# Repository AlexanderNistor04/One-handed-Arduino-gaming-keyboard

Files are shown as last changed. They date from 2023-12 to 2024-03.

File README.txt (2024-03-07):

This repository is for a 3D printed one handed gaming keyboard with a thumbstick and a small display. The keyboard has 36 keys (the button inside the thumbstick is the 36th key) and isn't meant to be used for typing but rather for gaming or other programs which don't require a full keyboard. 
The keyboard is built off of an Arduino pro micro with a micro usb port and has a male micro usb to female usb c internal adapter to allow the user to connect the keyboard to their computer with a usb c cable. The program for the Arduino is written in c++ and is included in this repository. 
The thumbstick functions as a mouse by default, moving the stick moves the cursor and clicking on the stick corresponds to a left click. Holding shift and clicking corresponds to a right click. 
All of the circuit boards are custom and their Gerber files are included. The circuits don't have any components on them, but were designed to have the user hand solder each component. The keyboard uses smd neopixel leds, which are the most difficult component to hand solder. The keyboard is designed to fit 3 pin mechanical keyboard switches and is made for hotswap switch sockets.
The previous iterations of the design are included as well, though many are not entirely complete and some files have been lost. 

This link leads to a MakerWorld model with the stl files of the latest version: https://makerworld.com/en/models/233790
This link leads to a thingiverse item with the stl files of the latest version of the 3d models: https://www.thingiverse.com/thing:6422238

Parts:
- arduino pro micro (https://www.amazon.com/gp/product/B01MTU9GOB/ref=ppx_yo_dt_b_search_asin_title?ie=UTF8&psc=1)
- male micro usb to female usb c adapter (https://www.amazon.com/Adapter-KUXIYAN-Connector-Compatible-Devices-Black/dp/B07VBV1PY5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)
- monochrome oled 12c display (https://www.amazon.com/gp/product/B08KLMJDGH/ref=ppx_yo_dt_b_search_asin_title?ie=UTF8&psc=1)
- 35 * 0.1uF ceramic capacitor (https://www.amazon.com/gp/product/B00RT02YIU/ref=ppx_yo_dt_b_search_asin_title?ie=UTF8&psc=1)
- 35 * WS2812B neopixel LED (https://www.amazon.com/gp/product/B00YC7ZXRM/ref=ppx_yo_dt_b_search_asin_title?ie=UTF8&psc=1)
- 36 * through-hole rectifier diode (https://www.amazon.com/gp/product/B071YWNBVM/ref=ppx_yo_dt_b_search_asin_title?ie=UTF8&psc=1)
- 470 ohm through hole resistor
- 36 * gateron yellow mechanical keyboard switche (you can use any full size 3-pin mechanical keyboard switch) (https://www.amazon.com/gp/product/B08JPJX296/ref=ppx_yo_dt_b_search_asin_title?ie=UTF8&psc=1)
- 35 * gateron mechanical switch hot-swap socket (https://www.amazon.com/gp/product/B0972HB9GY/ref=ppx_yo_dt_b_search_asin_title?ie=UTF8&psc=1)
- mechanical keyboard keycap set (I used a hyperx pudding keycap set but you can use any mechanical keyboard keycap set) (https://www.amazon.com/gp/product/B087QTR4CT/ref=ppx_yo_dt_b_search_asin_title?ie=UTF8&psc=1)
- screw-in keyboard stabilizer kit (https://www.amazon.com/gp/product/B08MWDGBJ8/ref=ppx_yo_dt_b_search_asin_title?ie=UTF8&psc=1)
- dual potentiometer analog thumbstick w/ button (https://www.amazon.com/gp/product/B06XH1NTFY/ref=ppx_yo_dt_b_search_asin_title?ie=UTF8&psc=1)
- thumbstick cap (https://www.amazon.com/gp/product/B083P4K9YR/ref=ppx_yo_dt_b_search_asin_title?ie=UTF8&psc=1)
- male pin headers (https://www.amazon.com/gp/product/B074HVBTZ4/ref=ppx_yo_dt_b_search_asin_title?ie=UTF8&psc=1)
- 9 * m3 nuts and bolts (https://www.amazon.com/Socket-Screws-Assortment-Button-Assorted/dp/B0BMQGV4SW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)

Building Instructions:
1. Solder the neopixel LEDs onto the primary circuit board. It's easiest to solder the neopixels first because they're the most dificult component to solder and should be done on a flat pcb, though this is not strictly necessary. The neopixels need to be oriented such that the small triangle indent on each neopixel is on the bottom right corner. 
2. Solder the diodes to the primary and secondary pcbs. The annode (negative side) (the side with the silver making) should be facing downwards for each diode. The diodes can be on either the front or the back of the pcb, except for the diode next to the shift key and the diode on the secondary pcb, which must be facing the backside of the board to avoid interference with other components.
3. Solder the hotswap sockets to the back of the primary pcb. The sockets should only be able to fit in one way, so there's no need to worry about soldering them backwards.
4. Solder the capacitors onto the back of the primary board. The capacitors must be on the backside of the board to not interfere with the keys. Most small, ceramic capaitors are not polar, so the capacitors can be soldered either way.
5. Solder the arduino to the back of the primary pcb. When looking at the back of the primary pcb, the port of the arduino should be facing right.
6. Solder the resistor to the back of the primary pcb.
7. Solder the display to the front of the primary pcb. Place the screen spacer 3d printed piece underneath the display while soldering to help keep the display level. Keep the spacer underneath the display to ensure it stays in place while in use. 
8. Solder the thumbstick to the secondary pcb. 
9. Solder the secondary pcb to the main pcb using some pin headers.
10. Attach the shift key stabilizer to the pcb.
11. Insert the female usb c end of the adapter into the main body of the keyboard such that the rest of the adapter lays on the inside of the body and the female end is flush with the outside of the body. It helps to heat the inside of the hole with a soldering iron to assist this process. It should be a very stiff fit and can be difficult to insert. 
12. Plug the male micro usb end of the adapter into the arduino and place the pcb into the main body.
13. Place the thumbstick cap onto the thumbstick. The thumbstick may be too wide to fit, in which case it can be trimmed and sanded down to fit. 
14. Place the spacer plate on top of the pcb.
15. Place the main plate on top of the spacer plate and insert the switches into the main plate and pcb. Be careful to keep the swiches completely vertical when pressing them in as it is easy to bend the pins. 
16. Optionally attach the wrist rest and stand and secure the keyboard shut with 9 screws.
17. Install the keycaps. 
18. Attach the keyboard into a computer and upload the code to the arduino. To do this, install Arduino IDE from the arduino website and plug the keyboard in. Open the library manager and make sure all the included libraries are installed. Then, select Arduino Leonardo in the boards menu and upload the code.

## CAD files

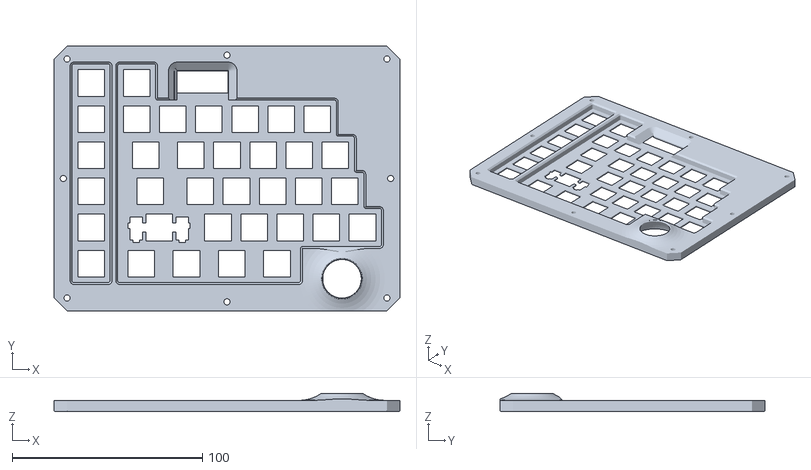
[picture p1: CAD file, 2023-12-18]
Keyboard v8/Main Plate.stl
182.0 x 139.5 x 9.71

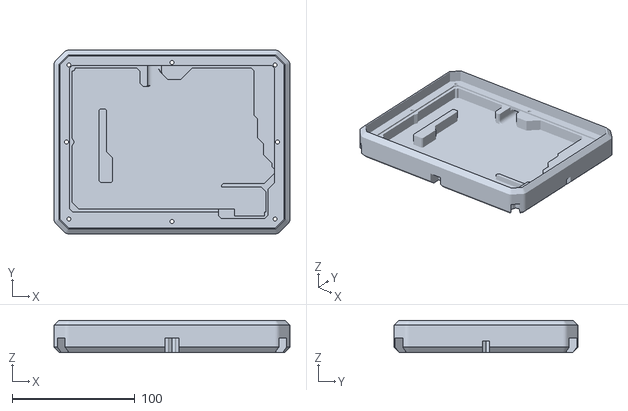
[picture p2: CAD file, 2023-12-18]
Keyboard v8/Main Body.stl
192.5 x 150.0 x 26.5

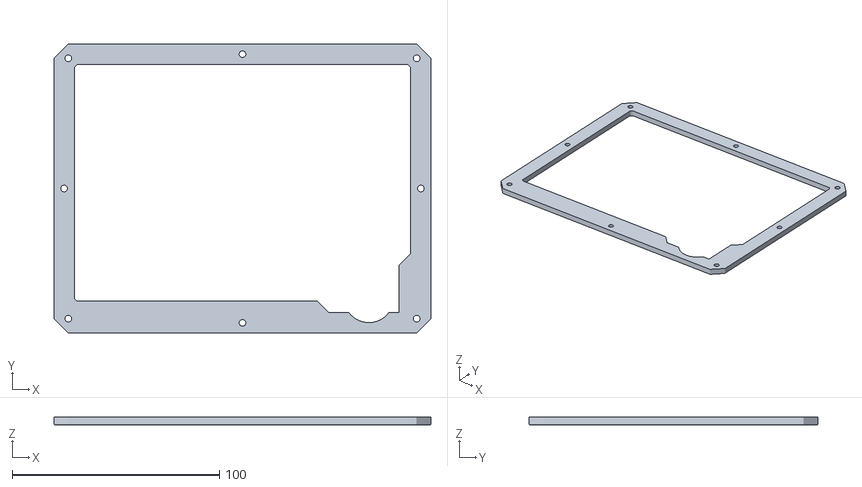
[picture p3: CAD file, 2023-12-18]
Keyboard v8/Spacer Plate.stl
182.0 x 139.5 x 4.00

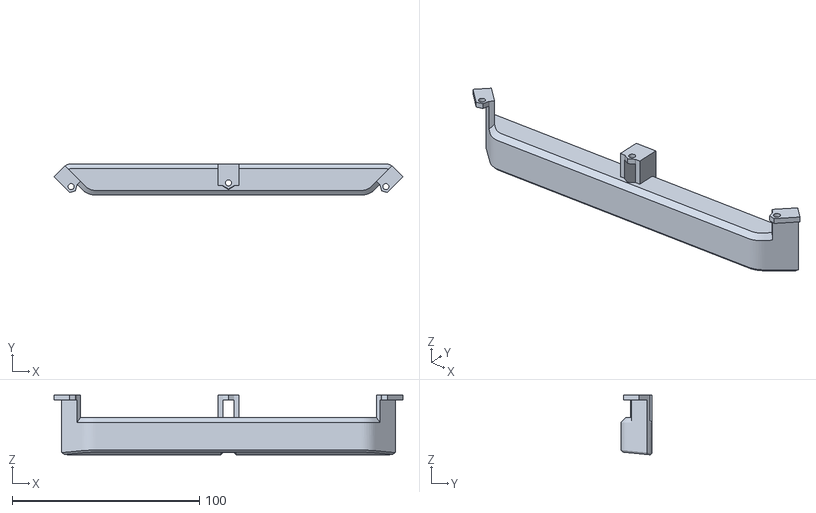
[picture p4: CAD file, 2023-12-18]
Keyboard v8/Stand.stl
186.5 x 16.7 x 31.9

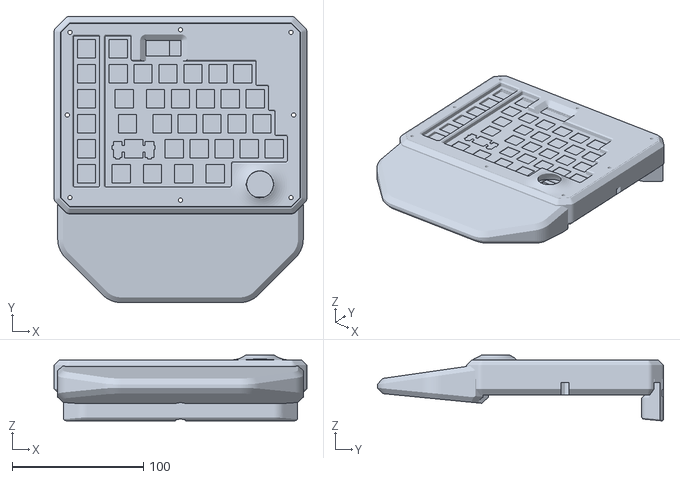
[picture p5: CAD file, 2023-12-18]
Keyboard v8/Keyboard v8.stl
192.5 x 217.8 x 50.1

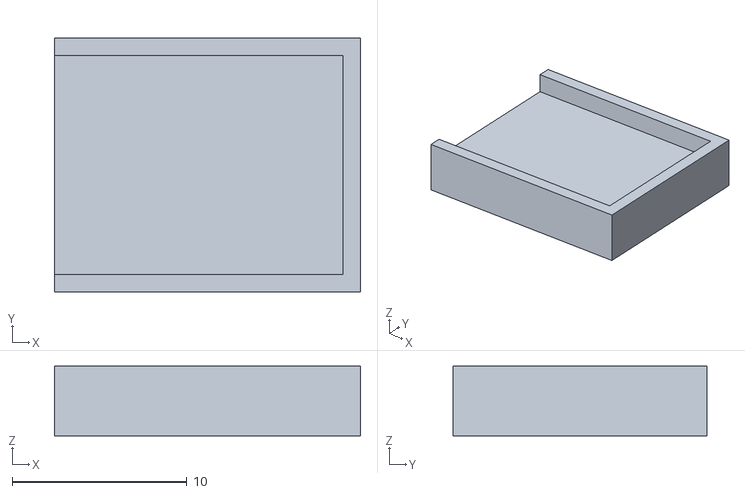
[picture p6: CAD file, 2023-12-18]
Keyboard v8/Screen Spacer.stl
17.5 x 14.5 x 4.00

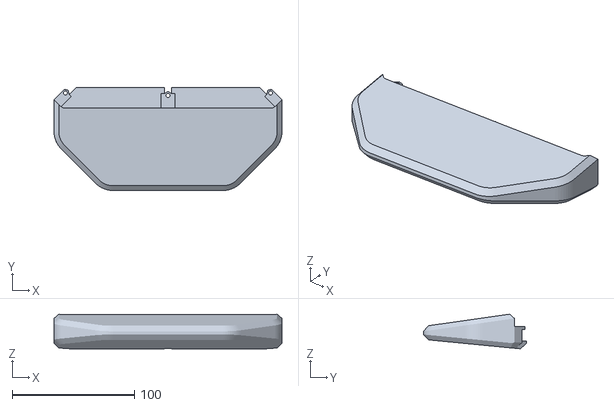
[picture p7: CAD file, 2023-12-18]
Keyboard v8/Wrist Rest.stl
186.8 x 84.4 x 28.4

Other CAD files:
Keyboard v2/Main Board Plate v2.f3d
Keyboard v2/Main Plate v4.f3d
Keyboard v2/Secondary Board Plate v1.f3d

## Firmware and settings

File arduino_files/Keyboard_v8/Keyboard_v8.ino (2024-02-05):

// Author: Alexander Nistor
#include <Keyboard.h>
#include <Mouse.h>
#include <SPI.h>
#include <Wire.h>
#include <Adafruit_GFX.h>
#include <Adafruit_SSD1306.h>
#include <Adafruit_NeoPixel.h>
#define numOfLEDs 35
Adafruit_NeoPixel pixels = Adafruit_NeoPixel(numOfLEDs,10, NEO_GRB + NEO_KHZ800);
Adafruit_SSD1306 display(128, 32, &Wire, -1);
                                                     
byte inputs[] = {1, 0, 4, 5, 6, 7};//declaring inputs and outputs
byte outputs[] = {A2, A1, A0, 15, 14, 16};
#define inCount sizeof(inputs)
#define outCount sizeof(outputs)

char profile[6][6] = {  //layout grid for characters
     {'`', '1', '2', '3', '4', '5'},   //pin 1
     {179 ,'q', 'w', 'e', 'r', 't'},   //pin 0
     {193, 'a', 's', 'd', 'f', 'g'},   //pin 4
     {129, 'z', 'x', 'c', 'v', 'b'},   //pin 5
     {128,'\0', 130, ' ','\0', 177},   //pin 6
     {199, 198, 197, 196, 195, 194},   //pin 7
//pins A2   A1   A0   15   14   16
};
// this is a 2d array that keeps track of when a key is pressed down. When a key is pressed, its row and col are put into the array, and its value is asssigned to true, and then when the key is released, its value is assigned to false
bool keyDown[outCount][inCount];
// this represents the index for each LED, starting at 0 and going to 34
int LEDnum = 0;
// this represents the index for the profile
int profileNum = 0;
// this represents the index for the LED color. 0 is off, 1-6 are static colors, 7 is the rainbow wave thingy
int colorProfile = 7;
#define numOfProfiles 2
#define numOfColors 8
// these are the RGB values used by the LEDs for the ranbow function
int r, g, b;
// this counter is used as the time variable in the wave function for the rainbow effect
int counter;

// these store the analog stick position in terms of x and y
int xAnalog = 0;
int yAnalog = 0;
// these help calibrate the analog stick by centering it, defining a deazone, and setting sensitivity
#define xAnalogCalibrate -7
#define yAnalogCalibrate 4
#define xDeadZone 50
#define yDeadZone 50
#define xSensitivity 25
#define ySensitivity 25
// these are the different characters that the stick can press
char analogKeys[4] = {'6', '7', '8', '9'};
// this array stores the bool values of whether or not the stick has been tilted and in what direction, so that way you can keep track of when a key is pressed and released
bool tilt[4];
// these keep track of when certain modifier keys are pressed, which helps with functions
bool fn;
bool shift;
bool ctrl;
// counter for the scroll wheel which makes it so that it scrolls as a slower speed
int scrollCounter = 0;

//sets up the display and creates a String array that stores all the lines being displayed
#define numLines 4
String displayQueue[numLines];

void setup(){                
 
 for(int i=0; i<outCount; i++){    //declaring all the outputs and setting them high
    pinMode(outputs[i],OUTPUT);
    digitalWrite(outputs[i],HIGH);
  }
  for(int i=0; i<inCount; i++){     //declaring all the inputs and activating the internal pullup resistor
    pinMode(inputs[i],INPUT_PULLUP);
  }
  pinMode(A8,INPUT);
  pinMode(A9,INPUT);
 
  Serial.begin(9600);               //establishing Serial link and initializing keyboard
  Keyboard.begin();
  Mouse.begin();
  pixels.begin();
  display.begin(SSD1306_SWITCHCAPVCC, 0x3C);

// display setup
  display.clearDisplay();
  display.setTextSize(1);
  display.setTextColor(SSD1306_WHITE);
  display.setCursor(0, 0);
  display.display();
}

//Main loop going through all the keys, then waiting 0.5ms
void loop() {
  for (int i = 0; i < outCount; i++){    
    digitalWrite(outputs[i], LOW);   //setting one row low
    delayMicroseconds(5);           //giving electronics time to settle down
    for(int j = 0; j < inCount; j++){
      if(digitalRead(inputs[j]) == LOW && !keyDown[j][i]){
        keyPressed(j, i);
      }            //calling keyPressed function if one of the inputs reads low
      if(digitalRead(inputs[j]) == HIGH && keyDown[j][i]){   //resetting the key if it is not pressed any more
        resetKey(j, i);
      }
    }
    digitalWrite(outputs[i], HIGH);
    delayMicroseconds(500);
  }//setting the row high and waiting 0.5ms until next cycle

//goes through all the LEDs and updates them
  for(int i = 0; i < numOfLEDs; i ++){
    LEDnum = i;
    LEDs();
  }
  pixels.show();

//if on the rainbow LED mode
  if(colorProfile == 7){ 
    counter ++;
    if(counter > 1023){counter = 0;}
    r = waveFN(counter);
    g = waveFN(counter + (1023 / 3));
    b = waveFN(counter + 2 * (1023 / 3));
  }
 
  //this takes the inputs from the analog stick and centers it at 0, ranging from -512 to +512
  xAnalog = analogRead(A8) - 512 + xAnalogCalibrate;
  yAnalog = analogRead(A9) - 512 + yAnalogCalibrate;

  //these read the analog values to tell when the stick is tilted, then calls the tilt and release functions when necessary
  if(profileNum == 0){
  // if in the mouse mode, tilting the stick moves the cursor
    if(fn){
      scrollCounter ++;
      if(scrollCounter % 15 == 0){
      Mouse.move(0, 0, -yAnalog / 100);
      }
    }else{
      Mouse.move(xAnalog / xSensitivity, yAnalog / ySensitivity, 0);
    }
    // if not in mouse mode, tilting the stick presses keys instead
  }else{
    if(xAnalog <= -xDeadZone && !tilt[1]){tiltStick(1);}
    if(xAnalog > -xDeadZone && tilt[1]){releaseStick(1);}
    if(xAnalog >= xDeadZone && !tilt[3]){tiltStick(3);}
    if(xAnalog < xDeadZone && tilt[3]){releaseStick(3);}
    if(yAnalog <= -yDeadZone && !tilt[0]){tiltStick(0);}
    if(yAnalog > -yDeadZone && tilt[0]){releaseStick(0);}
    if(yAnalog >= yDeadZone && !tilt[2]){tiltStick(2);}
    if(yAnalog < yDeadZone && tilt[2]){releaseStick(2);}
  }

}
                                                                                                                                                                                                                                                                                                                                                                                                                                                       
//if a key is pressed, this Funtion is called and outputs to serial the key location, it also sends the keystroke if not already done so
void keyPressed(int row, int col){
  //this prints out the input value of the key, the output value, and the key being pressed
  Serial.print("press:   Output: ");
  Serial.print(row);
  Serial.print(" Input: ");
  Serial.print(col);
  Serial.print(" ");
  Serial.println(profile[row][col]);
  displayLines("press: " + String(profile[row][col]));
  //this lets the program know that the key has been pressed, so it'll know whether or not to release the key if the key isn't being pressed anymore
  keyDown[row][col] = true;
  // these change some bool variables which keep track of when specific mod keys are pressed which are used for special functions
  if(row == 4 && col == 1){fn = true;}
  if(row == 3 && col == 0){shift = true;}
  if(row == 4 && col == 0){ctrl = true;}
  // if FN and 1 are pressed, function 1 is called, which switches the color of the LEDs
  if(fn && row == 0 && col == 1){
    colorProfile++;
    Serial.println("function: 1");
    displayLines("function: 1");
    if(colorProfile > numOfColors - 1){colorProfile = 0;}
    displayLines("color: " + String(colorProfile));
    return;
  }
  // if FN and 2 are pressed, function 2 is called, which changes the function of the analog stick
  if(fn && row == 0 && col == 2){
    profileNum++;
    Serial.println("function: 2");
    displayLines("function: 2");
    if(profileNum > numOfProfiles - 1){profileNum = 0;}
    displayLines("profile: " + String(profileNum));
    return;
  }
  //if the board is in the mouse profile and the button under the stick is pressed, either a left click or a right click is sent. Left click by default, right click if shift is being held
  if(profileNum == 0 && row == 4 && col == 4){
    if(fn){
      Mouse.press(MOUSE_RIGHT);
    }else{
    Mouse.press(MOUSE_LEFT);
    }
  }
  //this actually presses the key
  Keyboard.press(profile[row][col]);
}
         
void resetKey(int row, int col){ //resetting the variables after key is released
  //this prints out the input, output, and the released key, which helps troubleshoot
  Serial.print("release: Output: ");
  Serial.print(row);
  Serial.print(" Input: ");
  Serial.print(col);
  Serial.print(" ");
  Serial.println(profile[row][col]);
  displayLines("release: " + String(profile[row][col]));
  //and this actually releases the key
  Keyboard.release(profile[row][col]);
  // this lets the program know that the key has actually been released, so it doesn't have to keep track of it anymore
  keyDown[row][col] = false;
  // sets these bool vars false once their respective key has been released
  if(row == 4 && col == 1){fn = false;}
  if(row == 3 && col == 0){shift = false;}
  if(row == 4 && col == 0){ctrl = false;}
  // releases the mouse press
  if(profileNum == 0 && row == 4 && col == 4){
    if(fn){
      Mouse.release(MOUSE_RIGHT);
    }else{
    Mouse.release(MOUSE_LEFT);
    }
  }
}

// presses the keys when the stick is tilted
void tiltStick(int index){
  Serial.print("stick tilt:    ");
  Serial.println(analogKeys[index]);
  displayLines("tilt: " + String(analogKeys[index]));
  Keyboard.press(analogKeys[index]);
  tilt[index] = true;
}

// releases the stick keys
void releaseStick(int index){
  Serial.print("stick release: ");
  Serial.println(analogKeys[index]);
  displayLines("release: " + String(analogKeys[index]));
  Keyboard.release(analogKeys[index]);
  tilt[index] = false;
}

//changes the color of the LEDs based on what the colorProfile var equals
void LEDs(){
  switch(colorProfile){
    case 1:
      pixels.setPixelColor(LEDnum, pixels.Color(255, 0, 0));
      break;
    case 2:
      pixels.setPixelColor(LEDnum, pixels.Color(255, 255, 0));
      break;
    case 3:
      pixels.setPixelColor(LEDnum, pixels.Color(0, 255, 0));
      break;
    case 4:
      pixels.setPixelColor(LEDnum, pixels.Color(0, 255, 255));
      break;
    case 5:
      pixels.setPixelColor(LEDnum, pixels.Color(0, 0, 255));
      break;
    case 6:
      pixels.setPixelColor(LEDnum, pixels.Color(255, 0, 255));
      break;
    case 7:
      pixels.setPixelColor(LEDnum, pixels.Color(r, g, b));
      break;
    default:
      pixels.setPixelColor(LEDnum, pixels.Color(0, 0, 0));
      break;
  }
}

// custom wave function used for the rainbow effect. function starts at 0, gradually increases to 255, holds at 255, gradually decreases to 0, holds at 0, then repeats
int waveFN(int i){
  int x = i % 1023;
  int y;
  if(x <= 255){
    y = x;
  }
  if(x > 255 && x <= 511){
    y = 255;
  }
  if(x > 511 && x <= 767){
    y = 767 - x;
  }
  if(x > 767 && x <= 1023){
    y = 0;
  }
  return y;
}

//Queues a new line on the display and pushes the other lines down to make space
void displayLines(String s){
  for(int i = numLines - 1; i > 0; i--){
    displayQueue[i] = displayQueue[i-1];
  }
  displayQueue[0] = s;

  display.clearDisplay();
  for(int i = 0; i < numLines; i++){
    display.setCursor(0, 8*i);
    display.print(displayQueue[i]);
  }
  display.display();
}
